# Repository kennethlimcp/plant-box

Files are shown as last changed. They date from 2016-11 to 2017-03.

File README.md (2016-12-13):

### Introduction

#### Features

- safe OTA firmware update - turns off all peripherals
- water tank height monitoring
- moisture level sensing
- RGB lightning

#### Components

1. [Particle Photon](https;//particle.io)
2. [Motor shield by Hootie81](https://github.com/Hootie81/Dual-DC-Motor)
3. [Power shield by @Hootie81](https://github.com/Hootie81/Power-Shield)
4. [Moisture sensor](https://www.dfrobot.com/index.php?route=product/product&filter_name=SEN0114&product_id=599)
5. [Diaphragm Liquid Pump](http://www.sgbotic.com/index.php?dispatch=products.view&product_id=2119)
6. [Neopixel ring](https://www.adafruit.com/products/1643)

#### Pinout

| Peripheral|Pin| Photon USB|Pin|Peripheral|
| :---:|:-:|:---:|:--:|:---:|
||Vin||3V3||
||GND||RST||
||TX||VBAT||
||RX||GND||
||WKP||D7||
||DAC||D6||
|SPI MOSI|A5||D5||
|SPI MISO|A4||D4||
|SPI SCK|A3||D3||
|SPI SS|A2||D2|ECHO|
|Moisture sensor|A1||D1|TRIG|
|Motor SS|A0||D0|Neopixel|

#### Resources

1. [Firebase <-> Particle Cloud tutorial](https://github.com/rickkas7/firebase_tutorial)
2. [pulseIn for ultrasonic sensor](https://gist.github.com/technobly/349a916fb2cdeb372b5e)
3. [Spark Interval Timer](https://github.com/pkourany/SparkIntervalTimer)

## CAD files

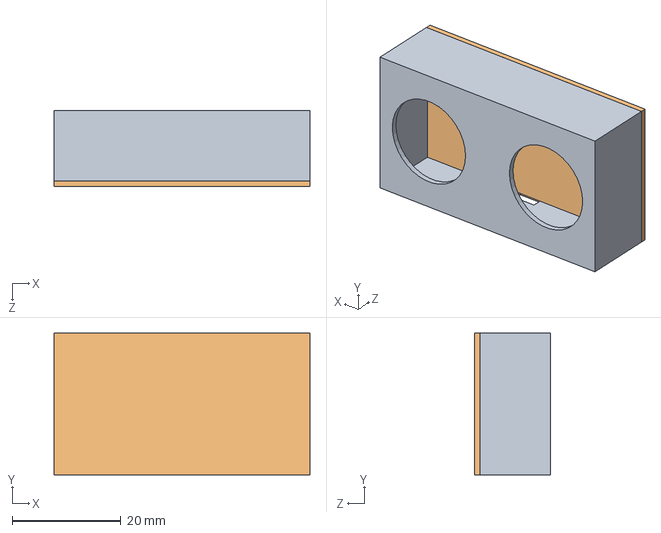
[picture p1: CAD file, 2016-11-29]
CAD drawings/PB - ultrasonic casing.SLDASM
47.0 x 26.0 x 14.0 mm
PB - ultrasonic mount
cover

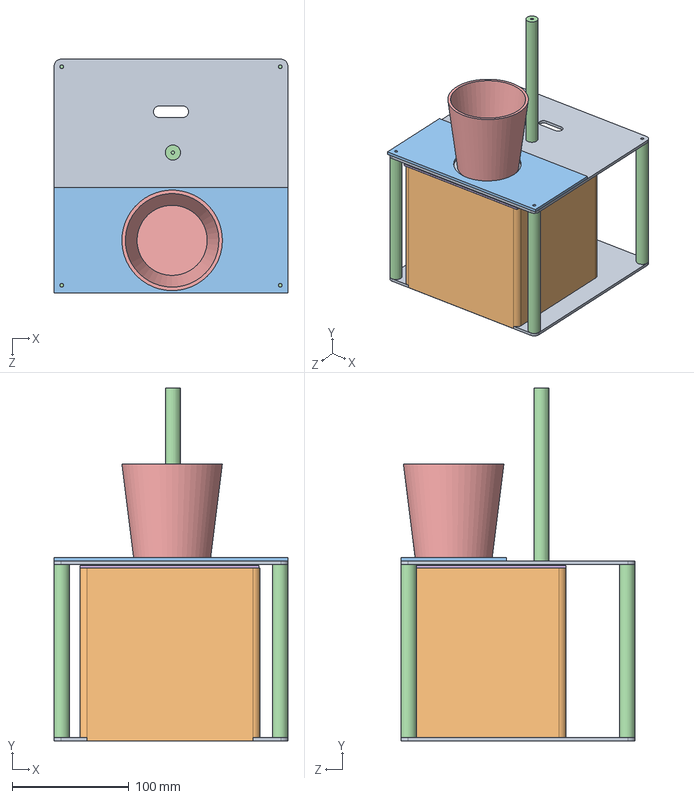
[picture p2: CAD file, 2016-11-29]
CAD drawings/PB - assembly.SLDASM
200.0 x 302.0 x 200.0 mm
PB - base plate x 2
PB - water tank
PB - pot slot
PB - leg x 5
PB - curved water funnel

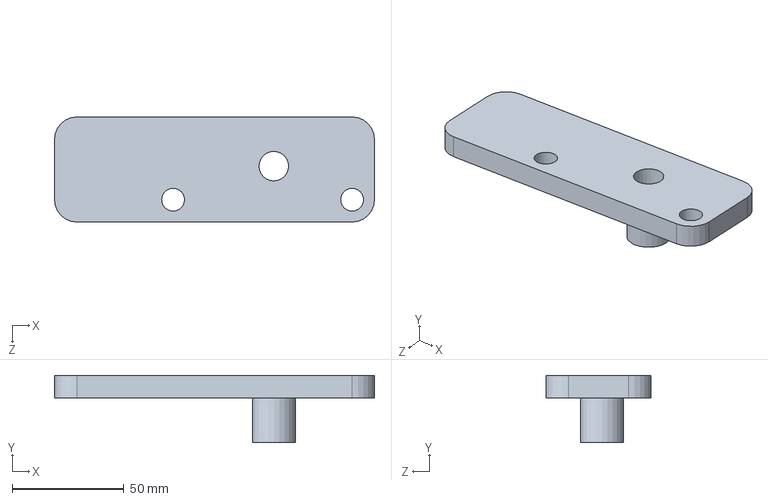
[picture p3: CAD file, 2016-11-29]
CAD drawings/PB - mounting.SLDPRT
143.0 x 30.0 x 47.0 mm

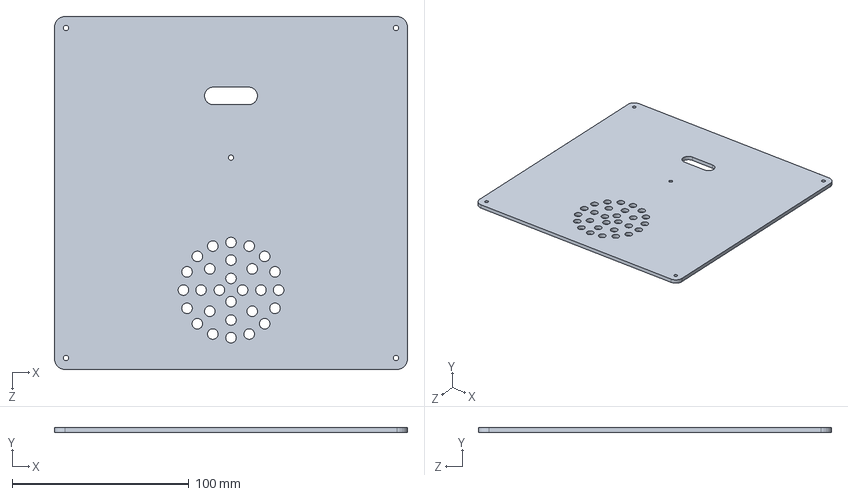
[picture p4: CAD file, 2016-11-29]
CAD drawings/PB - base plate.SLDPRT
200.0 x 3.00 x 200.0 mm

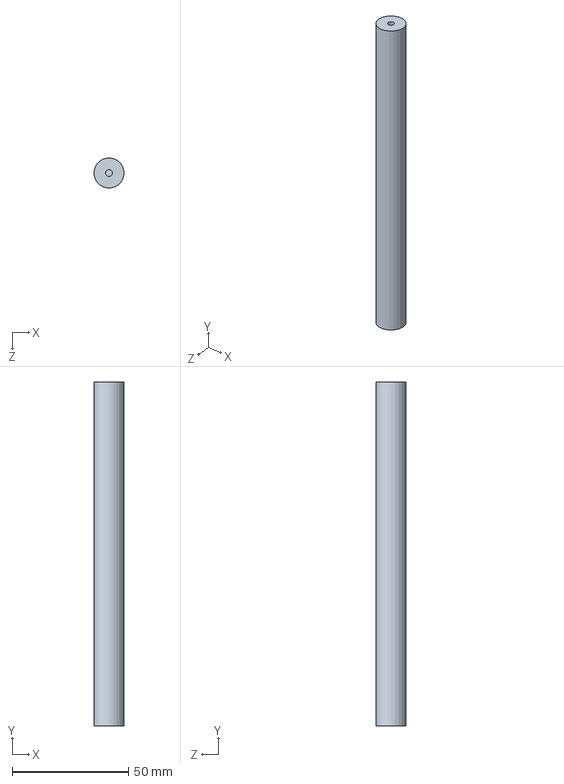
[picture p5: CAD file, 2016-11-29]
CAD drawings/PB - leg.SLDPRT
13.0 x 148.0 x 13.0 mm

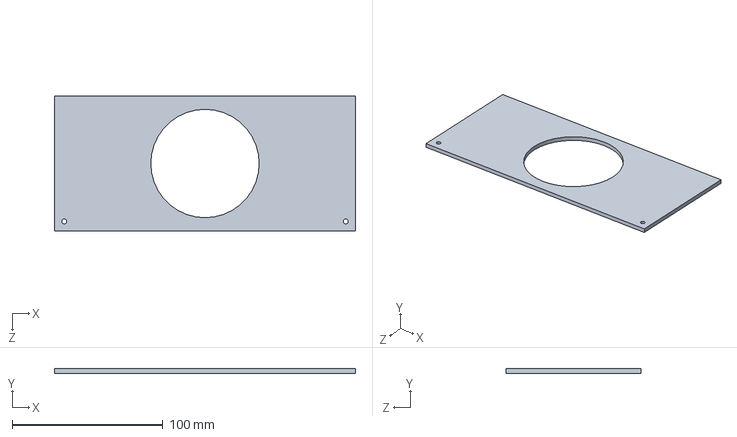
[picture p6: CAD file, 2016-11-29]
CAD drawings/PB - pot slot.SLDPRT
200.0 x 3.00 x 90.0 mm

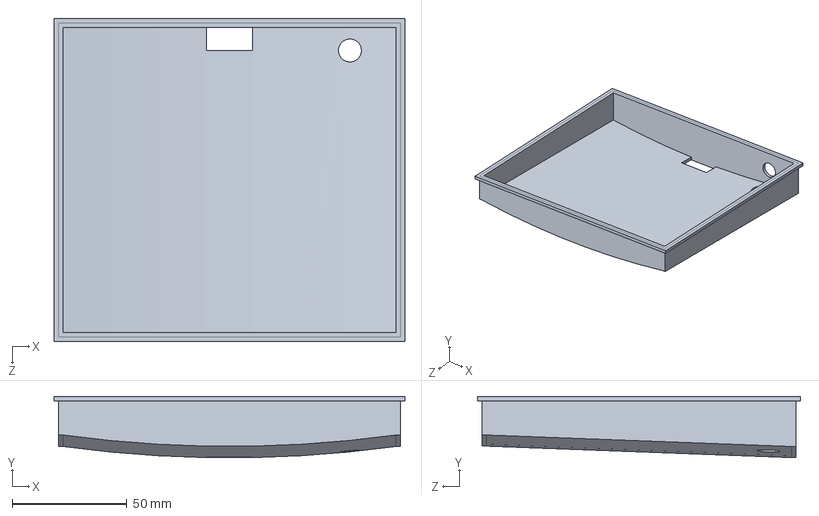
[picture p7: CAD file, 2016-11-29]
CAD drawings/PB - curved water funnel.SLDPRT
153.0 x 26.7 x 140.9 mm

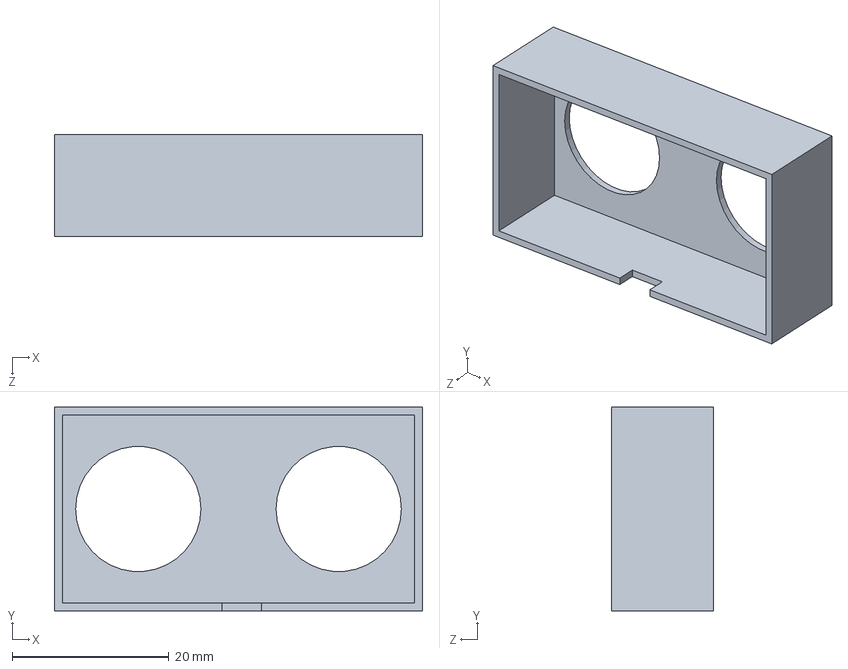
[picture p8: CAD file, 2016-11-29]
CAD drawings/PB - ultrasonic mount.SLDPRT
47.0 x 26.0 x 13.0 mm

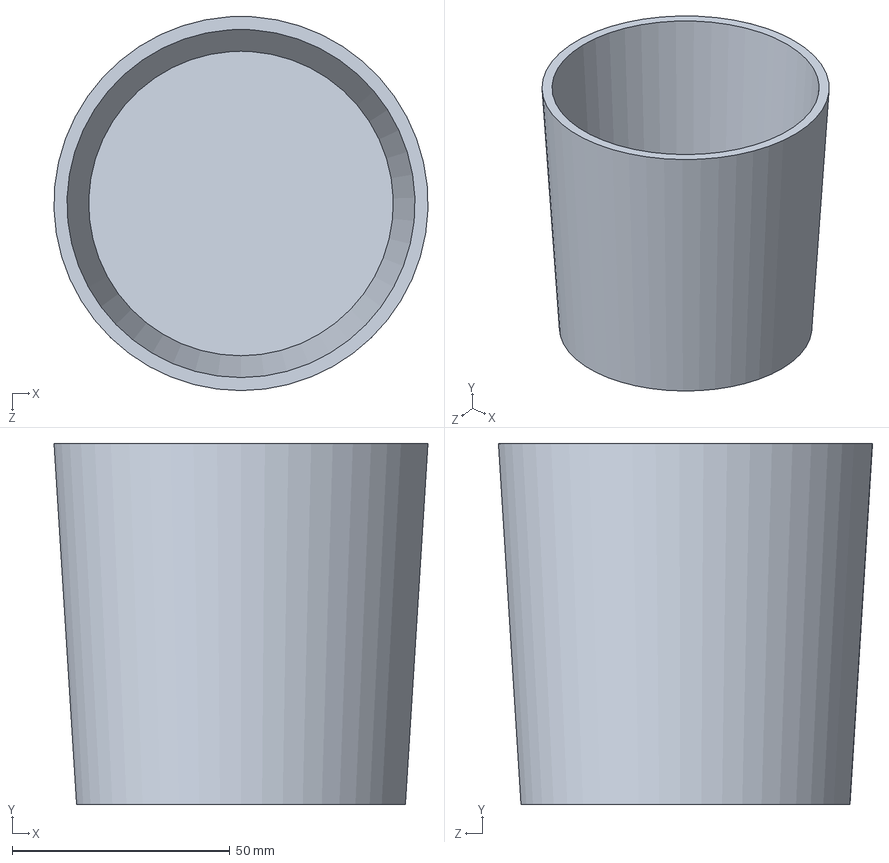
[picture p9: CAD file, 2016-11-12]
CAD drawings/PB - pot.SLDPRT
86.0 x 83.0 x 86.0 mm

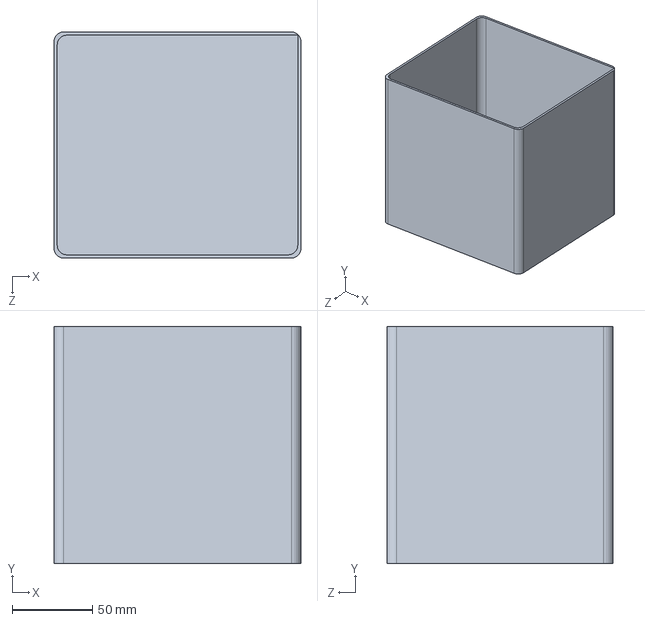
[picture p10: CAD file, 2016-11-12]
CAD drawings/PB - water tank.SLDPRT
154.0 x 148.0 x 141.0 mm

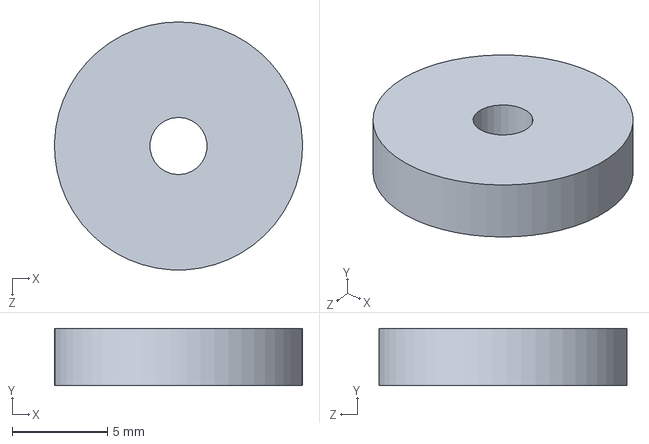
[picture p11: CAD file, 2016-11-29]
CAD drawings/PB - space washer.SLDPRT
13.0 x 3.00 x 13.0 mm

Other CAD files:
CAD drawings/Part2.sldprt
CAD drawings/cover.sldprt
CAD drawings/DXF/PB - base plate.DXF
CAD drawings/DXF/PB - mounting.DXF
CAD drawings/DXF/PB - pot slot.DXF

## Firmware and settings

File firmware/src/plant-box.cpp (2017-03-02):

#include "SPI_Motor.h"
#include "neopixel-fn.h"
#include "functions.h"
#include "SparkIntervalTimer.h"


SYSTEM_MODE(SEMI_AUTOMATIC);
STARTUP(pinMode(PIXEL_PIN, INPUT));

SPI_Motor motor(A0);	//Hootie81's motor shield using A0 CS pin

#define moisturePin A1

unsigned long wifiCheckTime = 0;
unsigned long publishCheckTime = 0;
unsigned long getInfoCheckTime = 0;
unsigned long oldSixtySec = 0;
const unsigned long PUBLISH_PERIOD_MS = 30*60*1000;
const unsigned long GET_PERIOD_MS = 5000;

uint8_t retryCount = 0;
uint8_t height = 0;
String controlCommand = "";

//Function prototypes
void checkWiFi();
void otaHandler();
int plantControl(String cmd);
void processControl();
void turnOffPeripherals();
void publishData();
void rainbow(uint8_t wait);
void publishData();
void getData();
void updateRefillStatus(uint32_t a);
void infoHandler(const char *topic, const char *data);
void deviceNameHandler(const char *topic, const char *data);
uint32_t ping(pin_t trig_pin, pin_t echo_pin, uint32_t wait, bool info);

IntervalTimer lightsTimer;
bool sixtySecSignal = false;
bool lightsOffSignal = false;
bool requireRefill = false;

void sixtySecFunction() {
		sixtySecSignal = true;
}

void lightoffFunction() {
	lightsOffSignal = true;
}

void setup() {
	WiFi.on();
	System.disableUpdates();
 System.on(firmware_update_pending, otaHandler);

	led.begin();
 colorWipe(led.Color(255, 255, 255), 0); //on
	led.show(); // Initialize all pixels to 'off'

	Serial.begin(9600);
	pinMode(moisturePin, INPUT);
	pinMode(D7, OUTPUT);
	digitalWrite(D7, LOW);

	Particle.variable("height", height);
	Particle.function("control", plantControl);
 Particle.subscribe("spark/", deviceNameHandler);
 Particle.subscribe("hook-response/get-Pdata/0", infoHandler, MY_DEVICES);


	if (motor.begin()){
		Particle.publish("plant/status/motorShield", "detected");
		motor.resume();
		motor.A(STOP, 0);
	}
	else {
		Particle.publish("plant/status/motorShield", "missing");
	}
}

void loop() {
	checkWiFi();

	processControl();

	height = 8 - ping(D1, D2, 20, false);

	//publish information to firebase
	if(millis() - publishCheckTime > PUBLISH_PERIOD_MS) {
 	/*uint32_t height = 8 - ping(D1, D2, 20, false);*/

		if(height <= 2)
			updateRefillStatus(true);
		else
			updateRefillStatus(false);

		uint32_t moisture = analogRead(moisturePin);
		publishData(height, moisture);

		publishCheckTime = millis();
	}


	if(millis() - getInfoCheckTime > GET_PERIOD_MS) {
		getData();

		getInfoCheckTime = millis();

		requireRefill = !requireRefill;
		updateRefillStatus(requireRefill);
/*
		if(owner == "") {
					colorWipe(led.Color(0, 0, 0), 0); //off
					motor.A(0);
		}*/
	}

	if(millis() - oldSixtySec > 60*60*1000) {
		sixtySecFunction();
		oldSixtySec = millis();
	}

	if(sixtySecSignal) {
		if(owner == "") {
					/*colorWipe(led.Color(0, 0, 0), 0); //off*/
					motor.A(0);
		}
		else {
			double pumpDuration = constrain(waterSetting.toInt(), 0, 100);
			pumpDuration = 3.0*(pumpDuration/100.0);	//% of 3seconds which is the max pump turn on time

			motor.A(CW, 255);
			delay(pumpDuration*1000);
			motor.A(STOP, 0);
			/*int lightIntensity = constrain(lightSetting.toInt(), 0, 100);
			lightIntensity = map(lightIntensity, 0, 100, 0, 255);
			colorWipe(led.Color(lightIntensity, lightIntensity, lightIntensity), 0); //on
			lightsTimer.begin(lightoffFunction, 10*1000*2, hmSec);	//30s*/
			sixtySecSignal = false;
			lightsOffSignal = false;

			/*if (DEBUG) Particle.publish("plant001/value", String(lightIntensity) +  "," + String(pumpDuration));*/
			if(DEBUG) Particle.publish("plant-watered");
		}
	}

	/*if(lightsOffSignal) {
		colorWipe(led.Color(0, 0, 0), 0); //off
		lightsTimer.end();
		lightsOffSignal = false;

		if (DEBUG) Particle.publish("timer/lightsoff");
		}*/
}

void checkWiFi() {
		if(millis() - wifiCheckTime >= 1000){
			if(retryCount < 10){
				if(!WiFi.ready()){
					WiFi.connect();
					retryCount++;

				}
				else if (!Particle.connected()){
					Particle.connect();
					retryCount++;
				}
			}
			else{
				WiFi.off();
				retryCount = 0;
				WiFi.on();
			}
			wifiCheckTime = millis();
		}
}

void otaHandler () {
	turnOffPeripherals();

	System.enableUpdates();
	digitalWrite(D7, HIGH);
}

void turnOffPeripherals() {
	motor.A(STOP, 0);
	motor.standby();
 colorWipe(led.Color(0, 0, 0), 0); //off
	led.show();
}

void processControl() {
	if(controlCommand == "safemode") {
			turnOffPeripherals();
			System.enterSafeMode();
	}
	else if(controlCommand == "testlight") {
		rainbow(20);
		colorWipe(led.Color(0, 0, 0), 0); //off
		led.show();
	}
	else if(controlCommand == "testmotor") {
		motor.A(CW, 255);
		delay(3000);
		motor.A(STOP, 0);
	}
	else if(controlCommand == "motoron") {
		motor.A(CW, 255);
	}
	else if(controlCommand == "motoroff") {
		motor.A(0);
	}
	else if(controlCommand == "lighton") {
		colorWipe(led.Color(255, 255, 255), 0); //on
		led.show();
	}
	else if(controlCommand == "lightoff") {
		colorWipe(led.Color(0, 0, 0), 0); //off
		led.show();
	}
	controlCommand = "";
}

int plantControl(String cmd) {
		if(cmd == "safemode") {
			controlCommand = "safemode";
			return 1;
		}
		else if(cmd == "testlight") {
			controlCommand = "testlight";
			return 2;
		}
		else if(cmd == "testmotor") {
			controlCommand = "testmotor";
			return 3;
		}
		else if(cmd == "motoron") {
			controlCommand = "motoron";
			return 4;
		}
		else if(cmd == "motoroff") {
			controlCommand = "motoroff";
			return 5;
		}
		else if(cmd == "lighton") {
			controlCommand = "lighton";
			return 6;
		}
		else if(cmd == "lightoff") {
			controlCommand = "lightoff";
			return 7;
		}
			return -1;
}

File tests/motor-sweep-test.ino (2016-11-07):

#include "SPI_Motor.h"

SYSTEM_MODE(MANUAL);

SPI_Motor singleCard(A0);	//Hootie81's motor shield using A0 CS pin

void setup() {
	Serial.begin(9600);
	while (!Serial.available()) Particle.process();

	if (singleCard.begin()){
		Serial.println("Single card Initialised!");
	}
	else
		Serial.println("Single card not found :(");

	singleCard.resume();
	singleCard.A(STOP, 0);
	singleCard.A(CW);
}

void loop() {
	int i;

	singleCard.A(STOP, 0);

	Serial.println("Ramping up all motors now");
	for(i=0; i<255; i++){  //create a loop with a increasing number
		singleCard.A(i);
		Serial.println("Ramp up speed: " + String(i));
		delay(115); //ramp from 0 to 255 should take about 30sec (maybe as a guess!!)
	}

	Serial.println("Ramping Down all motors now");
	for(i=255; i>0; i--){
		singleCard.A(i);
		Serial.println("Ramp down speed: " + String(i));
		delay(115); //ramp from 0 to 255 should take about 30sec (maybe as a guess!!)
	}

	//singleCard.standby();
	//singleCard.resume();
}

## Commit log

2016-11-07 add: feature goodies!
    - safe firmware OTA
    - motorShield initialization check
    - wifi management
    - cloud control function
    - neopixel skeleton
2016-11-09 updates and fixes
    - correctly turns off neopixel now
    - added some cloud functions for testing
    [plant-box.cpp]
2016-11-12 add: :smiley_cat: drawings!
    It's saturday and i bring you our plant-box design :)
    [PB - assembly.SLDASM, PB - base plate.SLDPRT, PB - curved water funnel.SLDPRT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]
2016-11-12 remove: flatten fw
    - v2.0 lib format issue has been fixed so this shall go
    [motor-sweep-test.ino]
2016-11-21 add: ultrasonic baby!
2016-11-29 add: misc CAD drawings
    [PB - assembly.SLDASM, PB - base plate.DXF, PB - base plate.SLDPRT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]
2016-11-29 sprint: lots of goodies
    - prevent neopixel from lighting up on boot
    - publish to height and moisture to firebase
    [plant-box.cpp]
2016-11-30 fix: correct water height offset
    [plant-box.cpp]
2016-12-12 add: use Spark Interval Timer
2016-12-12 add: simulate 24 hours
    - cycles through 60s interval
    - light turns on for 30s
    - light intensity based on fb value
    - pump on duration based on fb value
2016-12-16 mod: set base height to 8cm
2017-01-23 mod: change daily behavior
    - turn on LED all the time due to indoor setting
    - water plant every hour
    - setup watering notification
    - reduce logs to every 30 min
2017-01-25 fix: STOP motor instead of powering it to 0
    [plant-box.cpp]
